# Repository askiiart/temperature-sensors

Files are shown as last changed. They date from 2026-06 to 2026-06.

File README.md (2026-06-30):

# Temperature Sensors

An nRF52840-based Zigbee temperature sensor for use with ESPHome, designed for efficiency

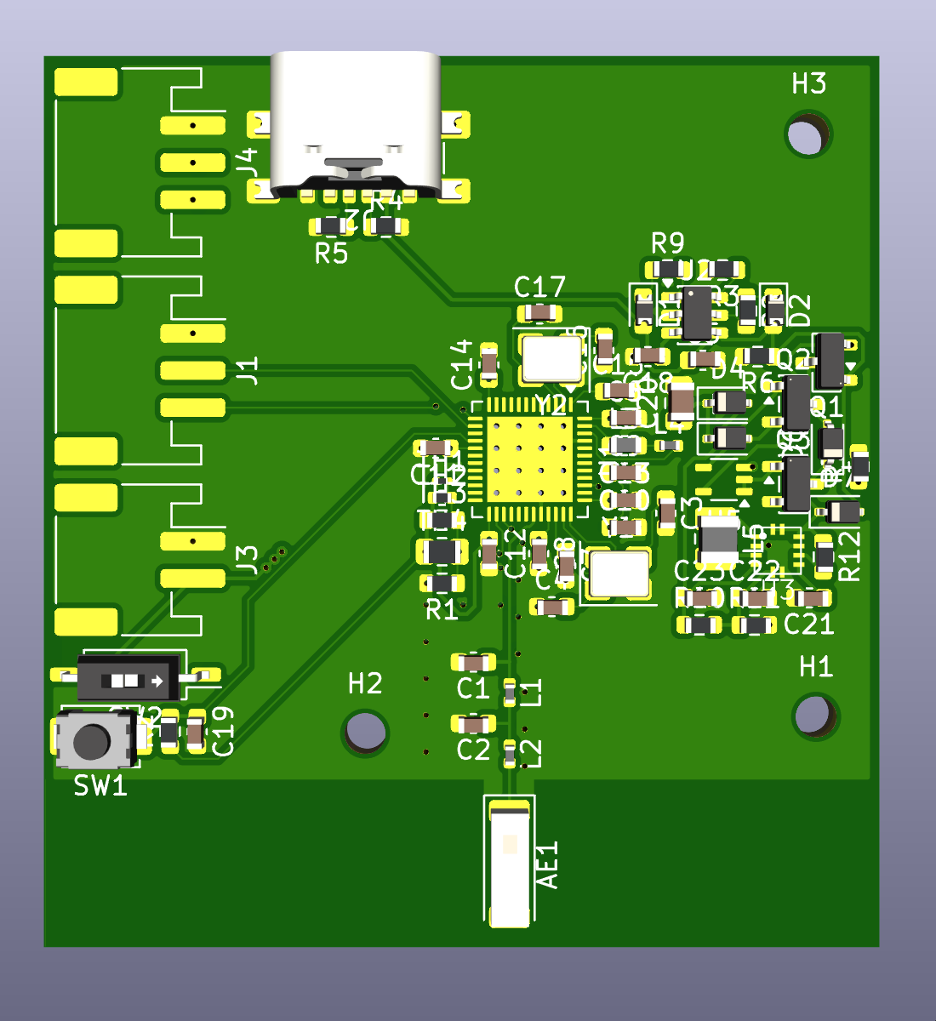
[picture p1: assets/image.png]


## Bill of Materials

|Name |Quantity needed|MOQ|Price |Quantity to order|Link |Total |
|---|---|---|---|---|---|---|
|2450AT43F0100001E |1 |1  |1.1034|1 |https://www.lcsc.com/product-detail/C17192881.html |1.1034 |
|32.768k crystal |1 |5  |0.2553|5 |https://www.lcsc.com/product-detail/C46257428.html |1.2765 |
|32M crystal |1 |10 |0.0564|10 |https://www.lcsc.com/product-detail/C42464320.html |0.564 |
|1pF cap |1 |100|0.0085|100 |https://www.lcsc.com/product-detail/C5137611.html |0.85 |
|1.2pF cap |1 |100|0.0038|100 |https://www.lcsc.com/product-detail/C1638.html |0.38 |
|20pF cap |2 |100|0.0089|100 |https://www.lcsc.com/product-detail/C5137583.html |0.89 |
|10uF cap |3 |50 |0.083 |50 |https://www.lcsc.com/product-detail/C1691.html |4.15 |
|1uF cap |1 |50 |0.0217|50 |https://www.lcsc.com/product-detail/C29936.html |1.085 |
|100pF cap |2 |50 |0.0174|50 |https://www.lcsc.com/product-detail/C576846.html |0.87 |
|47nF cap |1 |100|0.0077|100 |https://www.lcsc.com/product-detail/C576852.html |0.77 |
|100nF cap |5 |50 |0.0179|50 |https://www.lcsc.com/product-detail/C5137636.html |0.895 |
|100uF cap |1 |5  |0.3214|5 |https://www.lcsc.com/product-detail/C521072.html |1.607 |
|1nF cap |1 |100|0.0049|100 |https://www.lcsc.com/product-detail/C17702741.html |0.49 |
|10pF can |1 |100|0.0059|100 |https://www.lcsc.com/product-detail/C1634.html |0.59 |
|Green LED |1 |1  |0.29  |1 |https://www.digikey.com/en/products/detail/sunled/XZVG53W-8/4745971 |0.29 |
|Red LED |1 |1  |0.27  |1 |https://www.digikey.com/en/products/detail/sunled/XZMDK53W-8/4745952 |0.27 |
|Diodes |4 |50 |0.0112|50 |https://www.lcsc.com/product-detail/C191023.html |0.56 |
|JST S3B-PH-SM4-TB |2 |1  |0.57  |2 |https://www.digikey.com/en/products/detail/jst-sales-america-inc/S3B-PH-SM4-TB/926656 |1.14 |
|JST S2B-PH-SM4-TB |1 |5  |0.2055|5 |https://www.lcsc.com/product-detail/C295747.html |1.0275 |
|4.7nH inductor |1 |5  |0.0863|5 |https://www.lcsc.com/product-detail/C2043858.html |0.4315 |
|2.2nH inductor |1 |10 |0.0785|10 |https://www.lcsc.com/product-detail/C412264.html |0.785 |
|10uH inductor |1 |10 |0.0564|10 |https://www.lcsc.com/product-detail/C76798.html |0.564 |
|15nH inductor |1 |20 |0.0666|20 |https://www.lcsc.com/product-detail/C98055.html |1.332 |
|AO3401A (PMOS) |3 |20 |0.0371|20 |https://www.lcsc.com/product-detail/C347476.html |0.742 |
|1M resistor |3 |100|0.0037|100 |https://www.lcsc.com/product-detail/C2907003.html |0.37 |
|10k resistor |2 |100|0.0057|100 |https://www.lcsc.com/product-detail/C844918.html |0.57 |
|5.1k resistor |2 |100|0.0028|100 |https://www.lcsc.com/product-detail/C2907044.html |0.28 |
|100k resistor |1 |100|0.0025|100 |https://www.lcsc.com/product-detail/C2907088.html |0.25 |
|300 resistor |2 |100|0.0029|100 |https://www.lcsc.com/product-detail/C2930092.html |0.29 |
|560k resistor |1 |100|0.0025|100 |https://www.lcsc.com/product-detail/C23203.html |0.25 |
|180k resistor |1 |100|0.0027|100 |https://www.lcsc.com/product-detail/C2906999.html |0.27 |
|TS-1088-AR02016 (pushbutton)|1 |10 |0.0557|10 |https://www.lcsc.com/product-detail/C720477.html |0.557 |
|CHS-01B1 (slide switch) |1 |1  |0.7583|1 |https://www.lcsc.com/product-detail/C3312309.html |0.7583 |
|NTC themistor |1 |10 |0.0597|10 |https://www.lcsc.com/product-detail/C3152998.html |0.597 |
|nRF52840-QFAA-F-R7 |1 |1  |6.54  |1 |https://www.digikey.com/en/products/detail/nordic-semiconductor-asa/NRF52840-QFAA-F-R7/15929801|6.54 |
|TP4057 |1 |10 |0.0413|10 |https://www.lcsc.com/product-detail/C725791.html |0.413 |
|TPS63051RMWR |1 |1  |1.022 |1 |https://www.lcsc.com/product-detail/C139412.html |1.022 |
|SN74LVC1G00DCKR (inverter)  |1 |10 |0.0299|10 |https://www.lcsc.com/product-detail/C19829626.html |0.299 |
| | | | | | | |
|PCB |1 |1  |2 |1 |https://cart.jlcpcb.com/quote |2 |
| | | | | | | |
|JLCPCB shipping | | | | | |3.12 |
|LCSC shipping | | | | | |10.76 |
|Digikey shipping | | | | | |$4.99 |
| | | | | | | |
|Subtotal | | | | | |55.9992  |
|Total | | | | | |60.619134|

## Production notes

The layer stackup should be JLC0616H-3313.

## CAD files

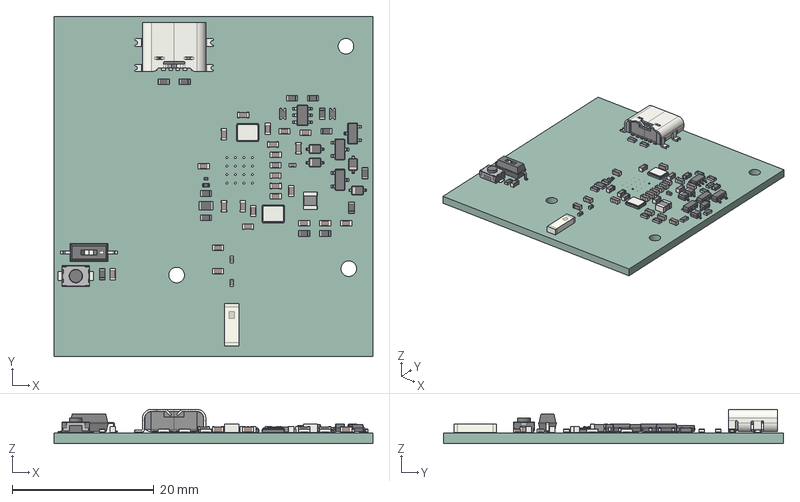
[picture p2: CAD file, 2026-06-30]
cad/pcb.step
45.0 x 48.0 x 4.85 mm
C_0603_1608Metric x 23
R_0603_1608Metric x 13
D_0603 x 2
SOT-23 x 3
SW_SPST_TS-1088-xR020
L_0603_1608Metric
L_0402_1005Metric x 3
Crystal_SMD_3225-4Pin_3.2x2.5mm x 2
D_SOD-323 x 4
L_1008_2520Metric
SW_DIP_SPSTx01_Slide_Copal_CHS_01B_W762mm_P127mm
R_0201_0603Metric
R_0805_2012Metric
Johanson_2450AT43F0100
USB_C_Receptacle_6P_TopMnt_Horizontal_GCT_USB4135-GF-A
TSOT-23-6
R_0402_1005Metric
temperature-sensors_PCB

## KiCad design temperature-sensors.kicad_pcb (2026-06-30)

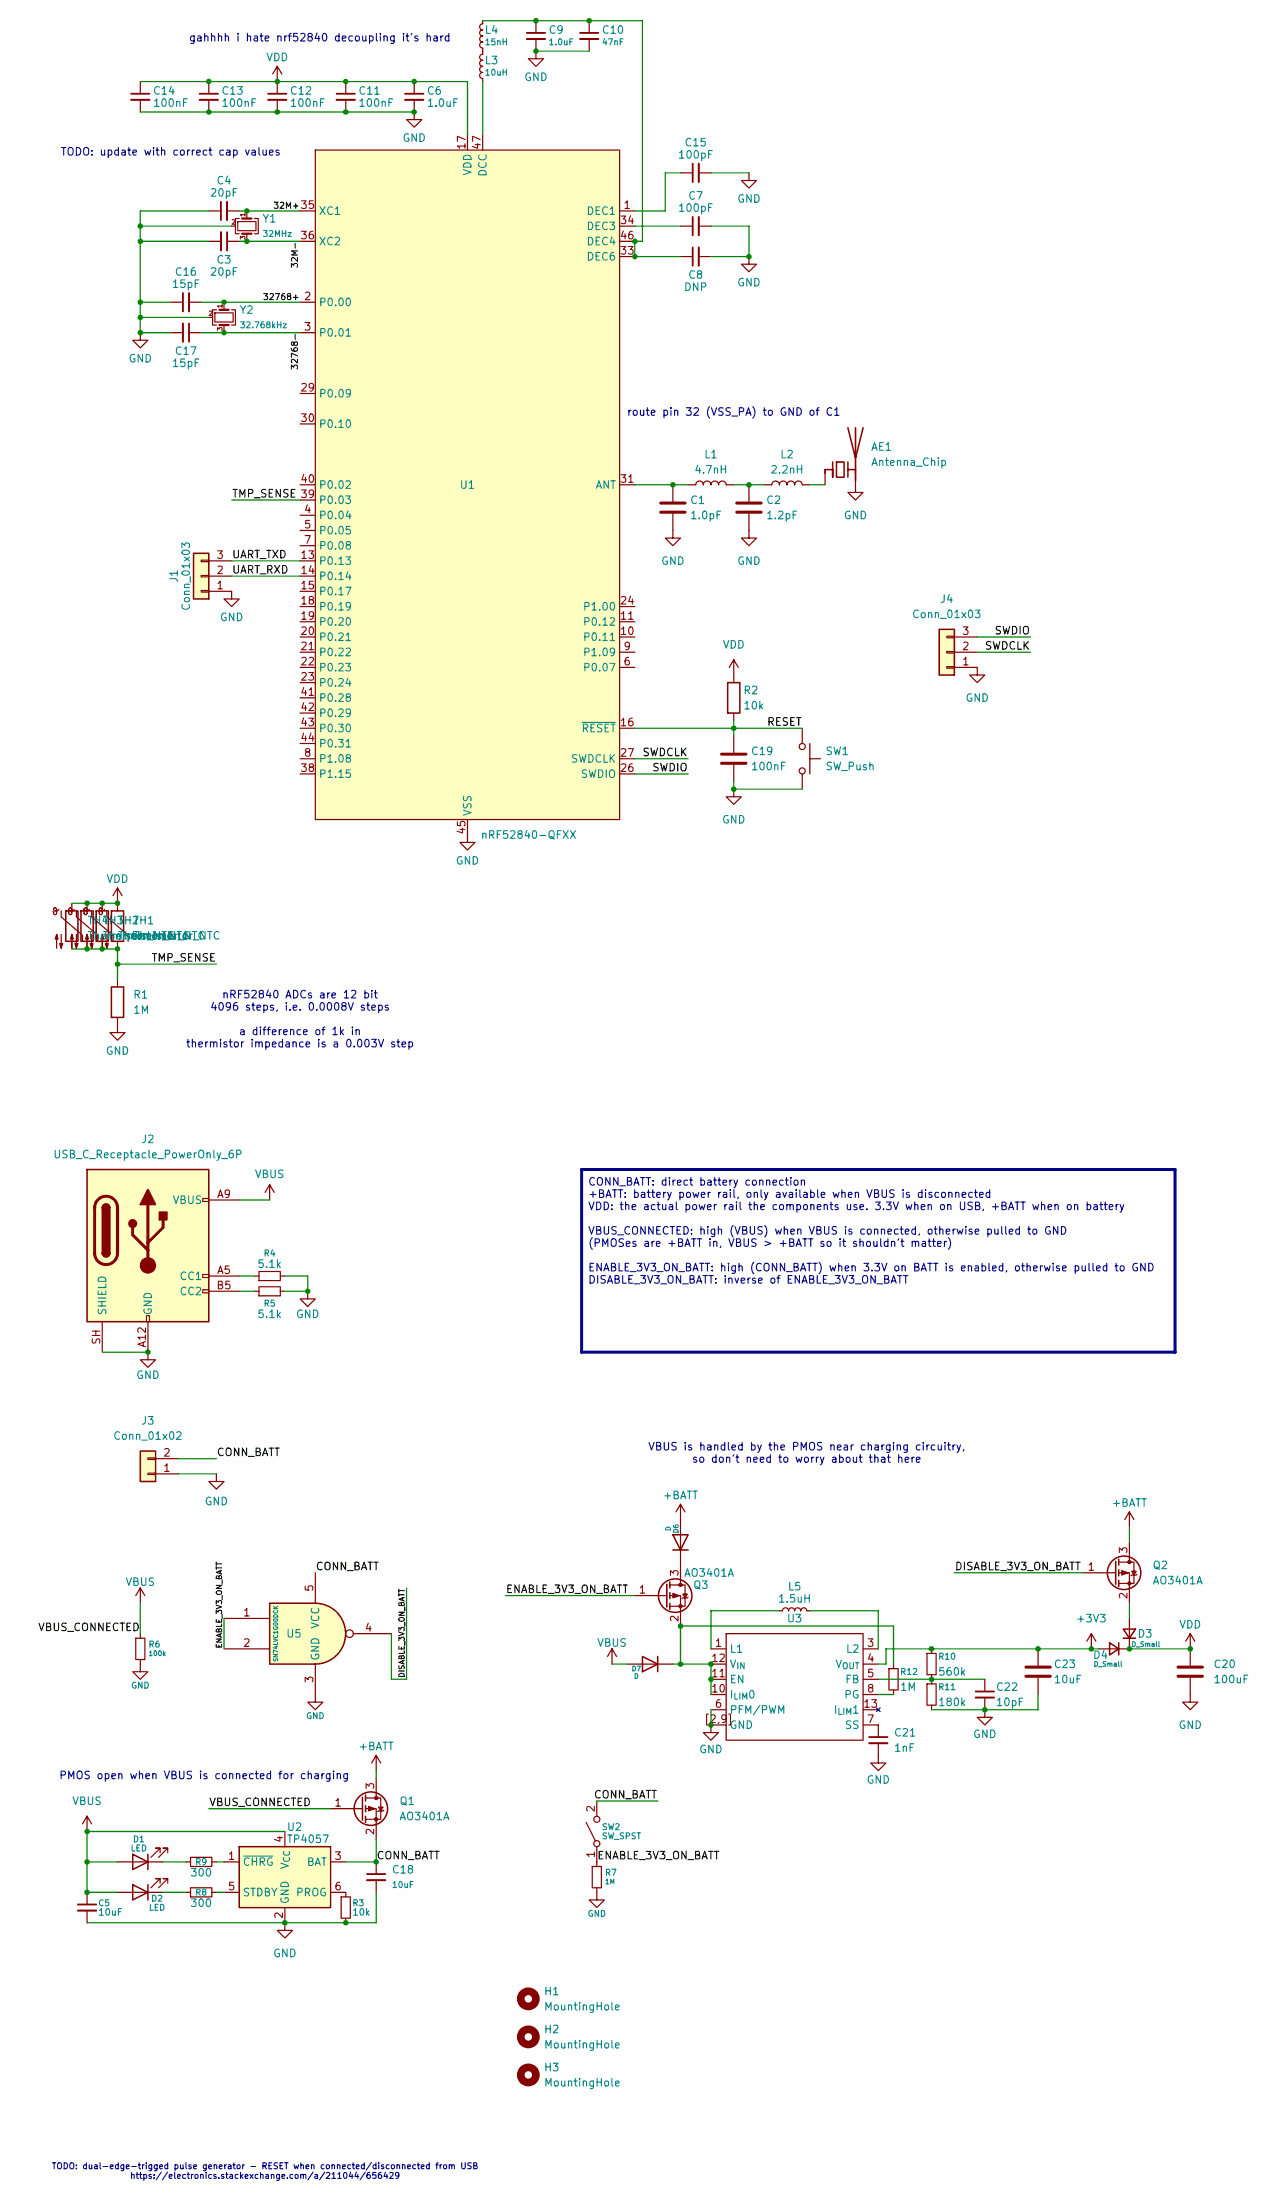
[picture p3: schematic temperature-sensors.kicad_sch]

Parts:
AE1: Antenna_Chip; Johanson_2450AT43F0100
C1: 1.0pF; C_0603_1608Metric
C2: 1.2pF; C_0603_1608Metric
C3, C4: 20pF; C_0603_1608Metric
C5, C18, C23: 10uF; C_0603_1608Metric
C6, C9: 1.0uF; C_0603_1608Metric
C7, C15: 100pF; C_0603_1608Metric
C8: DNP; C_0603_1608Metric
C10: 47nF; C_0603_1608Metric
C11, C12, C13, C14, C19: 100nF; C_0603_1608Metric
C16, C17: 15pF; C_0603_1608Metric
C20: 100uF; C_0805_2012Metric
C21: 1nF; C_0603_1608Metric
C22: 10pF; C_0603_1608Metric
D1, D2: LED; D_0603_1608Metric
D3, D4: D_Small; D_SOD-323
D6, D7: D; D_SOD-323
H1, H2, H3: MountingHole; MountingHole_2.2mm_M2_ISO7380
J1, J4: Conn_01x03; JST_PH_S3B-PH-SM4-TB_1x03-1MP_P2.00mm_Horizontal
J2: USB_C_Receptacle_PowerOnly_6P; USB_C_Receptacle_GCT_USB4135-GF-A_6P_TopMnt_Horizontal
J3: Conn_01x02; JST_PH_S2B-PH-SM4-TB_1x02-1MP_P2.00mm_Horizontal
L1: 4.7nH; L_0402_1005Metric
L2: 2.2nH; L_0402_1005Metric
L3: 10uH; L_0603_1608Metric
L4: 15nH; L_0402_1005Metric
L5: 1.5uH; L_1008_2520Metric
Q1, Q2, Q3: AO3401A; SOT-23
R1, R7, R12: 1M; R_0603_1608Metric
R2, R3: 10k; R_0603_1608Metric
R4, R5: 5.1k; R_0603_1608Metric
R6: 100k; R_0603_1608Metric
R8, R9: 300; R_0603_1608Metric
R10: 560k; R_0603_1608Metric
R11: 180k; R_0603_1608Metric
SW1: SW_Push; SW_SPST_TS-1088-xR020
SW2: SW_SPST; SW_DIP_SPSTx01_Slide_Copal_CHS-01B_W7.62mm_P1.27mm
TH1: Thermistor_NTC; R_0201_0603Metric
TH2: Thermistor_NTC; R_0402_1005Metric
TH3: Thermistor_NTC; R_0603_1608Metric
TH4: Thermistor_NTC; R_0805_2012Metric
U1: nRF52840-QFXX; QFN-48-1EP_6x6mm_P0.4mm_EP4.6x4.6mm_ThermalVias
U2: TP4057; TSOT-23-6
U3: TPS63051-QFN-12-HotRod
U5: SN74LVC1G00DCK; Texas_R-PDSO-G5_DCK-5
Y1: 32MHz; Crystal_SMD_3225-4Pin_3.2x2.5mm
Y2: 32.768kHz; Crystal_SMD_3225-4Pin_3.2x2.5mm

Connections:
+3V3: C23.1, D4.2 (A), R10.1, U3.4 (V_{OUT})
+BATT: D6.2 (A), Q1.3 (D), Q2.3 (D)
/32M+: C4.2, U1.35 (XC1), Y1.1
/32M-: C3.1, U1.36 (XC2), Y1.3
/32768+: C16.2, U1.2 (P0.00), Y2.1
/32768-: C17.1, U1.3 (P0.01), Y2.3
/CONN_BATT: C18.1, J3.2, Q1.2 (S), SW2.2 (B), U2.3 (BAT), U5.5 (VCC)
/DISABLE_3V3_ON_BATT: Q2.1 (G), U5.4
/ENABLE_3V3_ON_BATT: Q3.1 (G), R7.1, SW2.1 (A), U5.1, U5.2
/RESET: C19.1, R2.2, SW1.1, U1.16 (~RESET)
/SWDCLK: J4.2, U1.27 (SWDCLK)
/SWDIO: J4.3, U1.26 (SWDIO)
/TMP_SENSE: R1.1, TH1.2, TH2.2, TH3.2, TH4.2, U1.39 (P0.03)
/UART_RXD: J1.2, U1.14 (P0.14)
/UART_TXD: J1.3, U1.13 (P0.13)
GND: AE1.2 (PCB_Trace), C1.2, C2.2, C3.2, C4.1, C5.2, C6.2, C7.2, C8.2, C9.2, C10.2, C11.2, C12.2, C13.2, C14.2, C15.2, C16.1, C17.2, C18.2, C19.2, C20.2, C21.2, C22.2, C23.2, J1.1, J2.A12 (GND), J2.B12 (GND), J2.SH (SHIELD), J3.1, J4.1, R1.2, R3.2, R4.2, R5.2, R6.2, R7.2, R11.2, SW1.2, U1.32 (VSS_PA), U1.45 (VSS), U1.49 (VSS), U2.2 (GND), U3.2 (GND), U3.6 (PFM/PWM), U3.9 (GND), U3.[2,9] (GND), U5.3 (GND), Y1.2 (G), Y1.4 (G), Y2.2 (G), Y2.4 (G)
unnamed: AE1.1 (FEED), L2.2
unnamed: C2.1, L1.2, L2.1
unnamed: D1.1 (K), R9.1
unnamed: D2.1 (K), R8.1
unnamed: D3.2 (A), Q2.2 (S)
unnamed: D6.1 (K), Q3.3 (D)
unnamed: D7.1 (K), Q3.2 (S), R12.1, U3.10 (I_{LIM}0), U3.11 (EN), U3.12 (V_{IN})
unnamed: J2.A5 (CC1), R4.1
unnamed: J2.B5 (CC2), R5.1
unnamed: L3.2, L4.1
unnamed: C1.1, L1.1, U1.31 (ANT)
unnamed: L3.1, U1.47 (DCC)
unnamed: C15.1, U1.1 (DEC1)
unnamed: C7.1, U1.34 (DEC3)
unnamed: C8.1, C9.1, C10.1, L4.2, U1.33 (DEC6), U1.46 (DEC4)
unnamed: R3.1, U2.6 (PROG)
unnamed: R8.2, U2.5 (STDBY)
unnamed: R9.2, U2.1 (~CHRG)
unnamed: C22.1, R10.2, R11.1, U3.5 (FB)
unnamed: L5.1, U3.1 (L1)
unnamed: L5.2, U3.3 (L2)
unnamed: R12.2, U3.8 (PG)
unnamed: C21.1, U3.7 (SS)
VBUS: C5.1, D1.2 (A), D2.2 (A), D7.2 (A), J2.A9 (VBUS), J2.B9 (VBUS), Q1.1 (G), R6.1, U2.4 (V_{CC})
VDD: C6.1, C11.1, C12.1, C13.1, C14.1, C20.1, D3.1 (K), D4.1 (K), R2.1, TH1.1, TH2.1, TH3.1, TH4.1, U1.12 (VDD), U1.17 (VDD), U1.25 (VDD), U1.37 (VDD), U1.48 (VDD)

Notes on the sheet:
gahhhh i hate nrf52840 decoupling it's hard
VBUS is handled by the PMOS near charging circuitry, so don't need to worry about that here
TODO: update with correct cap values
route pin 32 (VSS_PA) to GND of C1
nRF52840 ADCs are 12 bit 4096 steps, i.e. 0.0008V steps a difference of 1k in thermistor impedance is a 0.003V step
CONN_BATT: direct battery connection +BATT: battery power rail, only available when VBUS is disconnected VDD: the actual power rail the components use. 3.3V when on USB, +BATT when on battery VBUS_CONNECTED: high (VBUS) when VBUS is connected, otherwise pulled to GND (PMOSes are +BATT in, VBUS > +B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
TODO: dual-edge-trigged pulse generator - RESET when connected/disconnected from USB https://electronics.stackexchange.com/a/211044/656429
PMOS open when VBUS is connected for charging

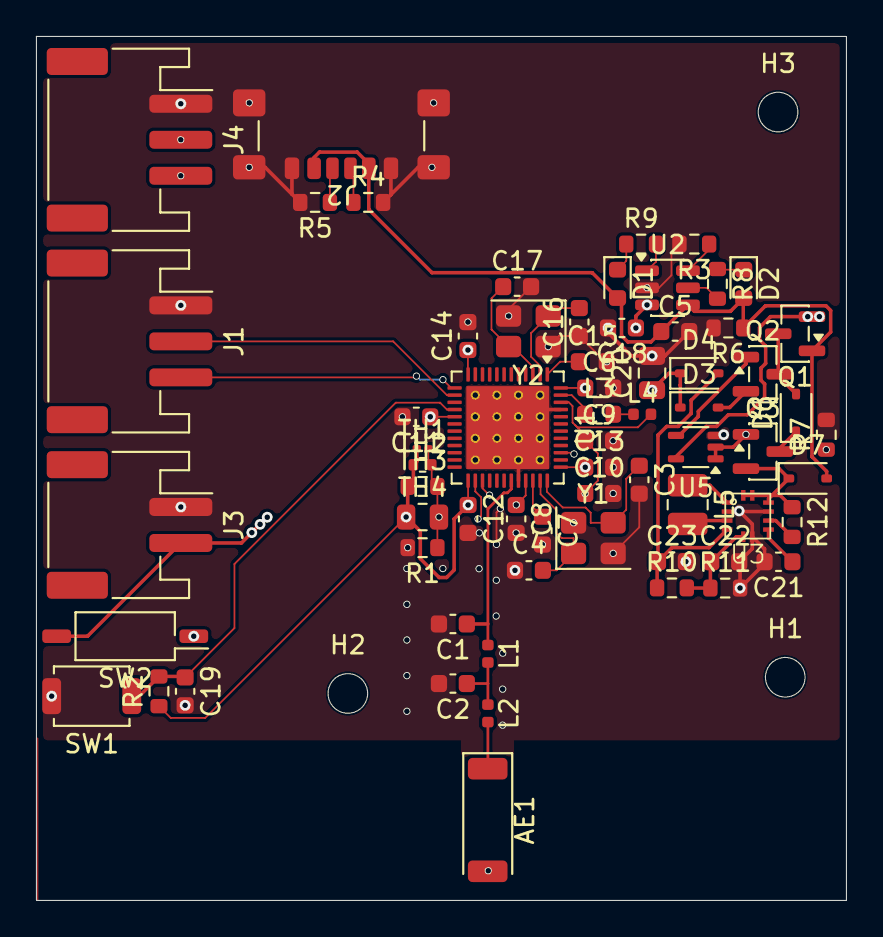
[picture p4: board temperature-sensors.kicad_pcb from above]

Board: 6 copper layers, 45.0 x 48.0 mm, 69 parts (0 on the bottom side), 41 nets.

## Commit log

2026-06-21 add actually decent power circuitry - can charge and power itself off USB simultaneously
    [temperature-sensors.kicad_sch]
2026-06-21 get rid of extra PMOS
    [temperature-sensors.kicad_sch]
2026-06-22 add a bunch of stuff idk i'm just committing
    [temperature-sensors.kicad_sch]
2026-06-28 finished schematic idk
    [temperature-sensors.kicad_sch]
2026-06-30 the pcb is pcb'd idkkkk
    [temperature-sensors.kicad_pcb, temperature-sensors.kicad_sch]
2026-06-30 add BOM and images and yeag
    [BOM.csv, BOM.ods, pcb.step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]
